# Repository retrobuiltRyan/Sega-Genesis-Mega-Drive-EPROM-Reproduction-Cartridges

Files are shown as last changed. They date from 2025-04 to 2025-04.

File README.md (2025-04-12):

# Sega-Genesis-Mega-Drive-EPROM-Reproduction-Cartridges
https://youtu.be/jw_2mUTdxVY

P1010174 - Copy

Solder Jumper example

Sega Genesis MegaDrive EPROM Cart PCB

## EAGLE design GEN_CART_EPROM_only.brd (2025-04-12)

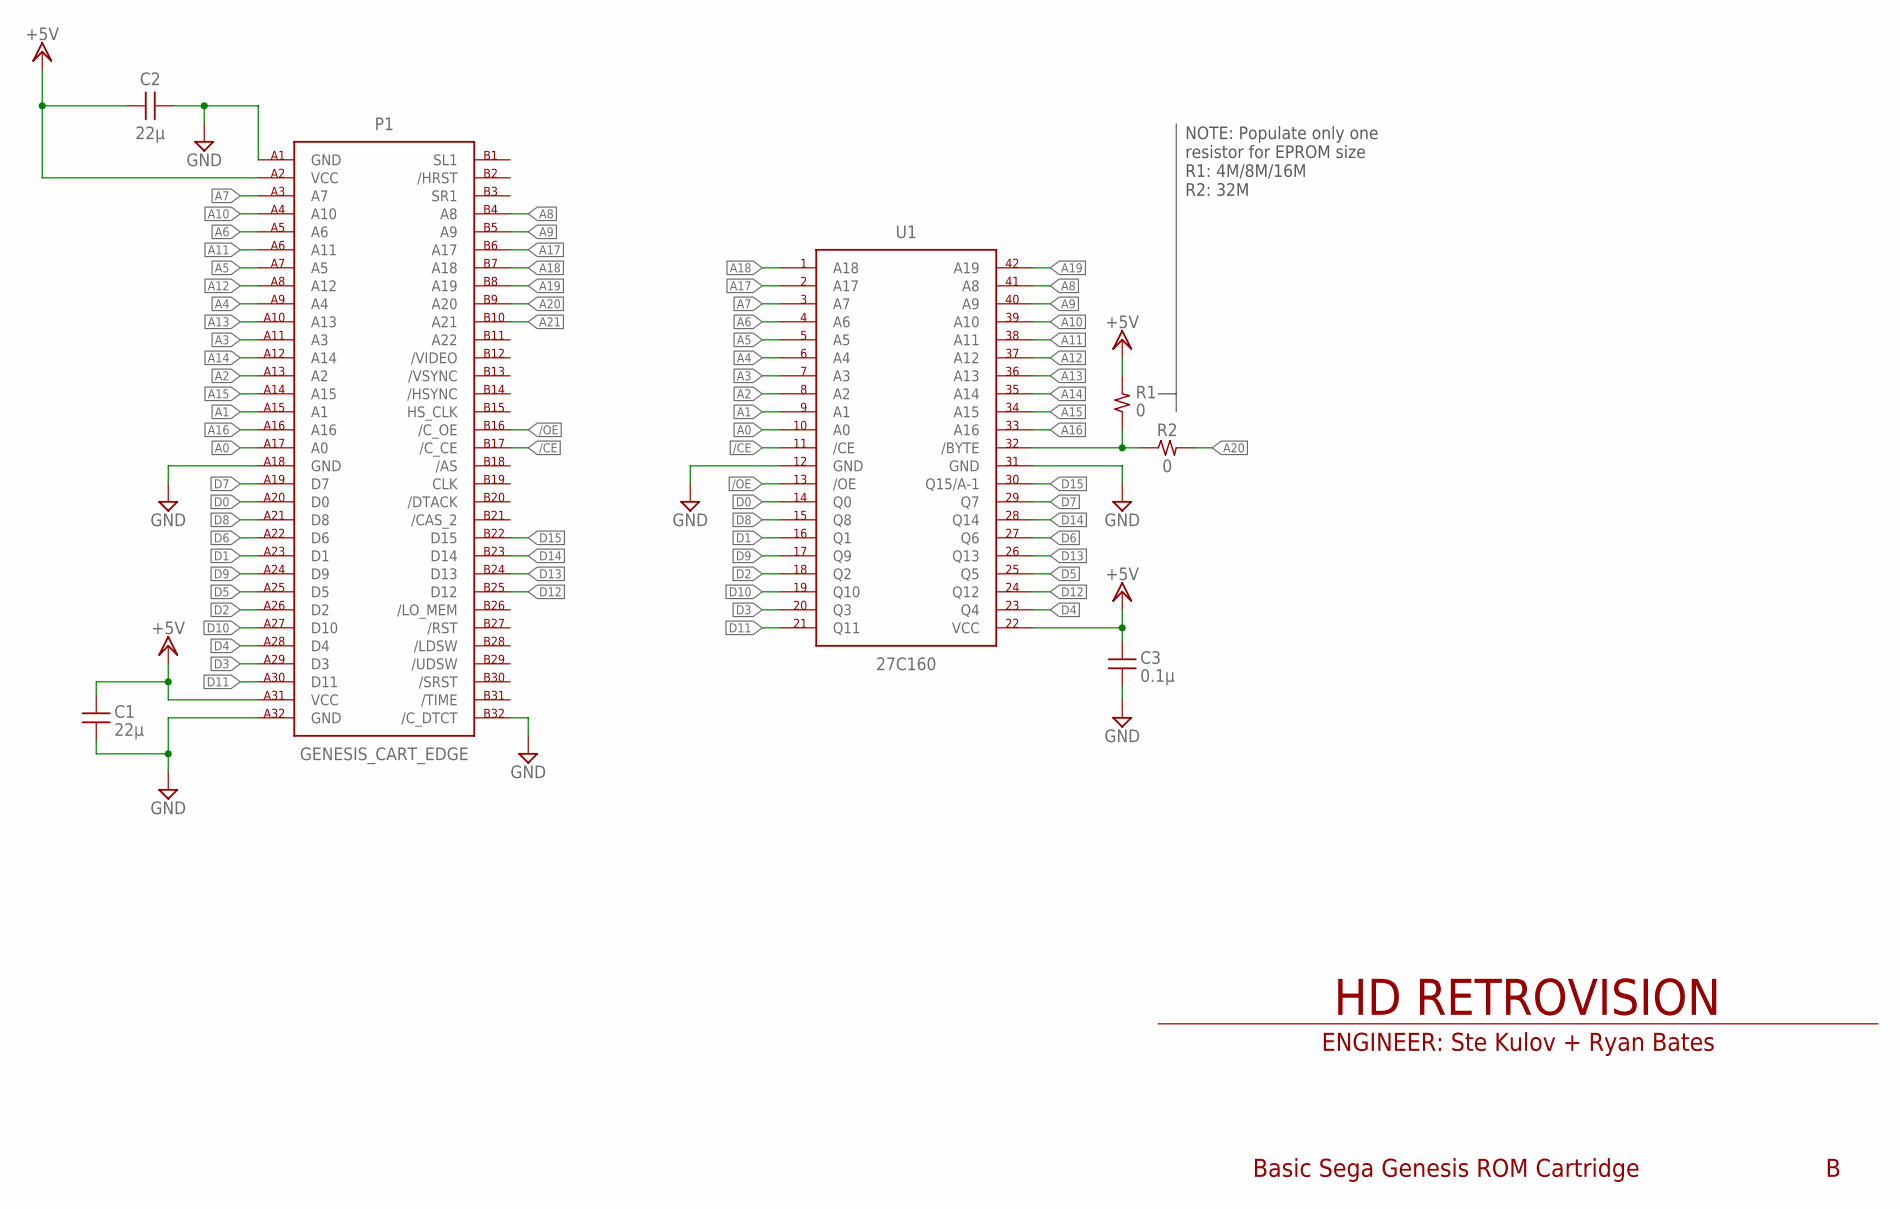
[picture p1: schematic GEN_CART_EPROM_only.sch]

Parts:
C1, C2: 22µ; CAP_SMD1210
C3: 0.1µ; CAP_SMD1210
P1: GENESIS_CART_EDGE
R1, R2: 0; RES_SMD0603
U1: 27C160; DIP_600MIL_42

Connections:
/CE: P1.B17 (/C_CE), U1.P$11 (/CE)
/OE: P1.B16 (/C_OE), U1.P$13 (/OE)
A0: P1.A17 (A0), U1.P$10 (A0)
A1: P1.A15 (A1), U1.P$9 (A1)
A2: P1.A13 (A2), U1.P$8 (A2)
A3: P1.A11 (A3), U1.P$7 (A3)
A4: P1.A9 (A4), U1.P$6 (A4)
A5: P1.A7 (A5), U1.P$5 (A5)
A6: P1.A5 (A6), U1.P$4 (A6)
A7: P1.A3 (A7), U1.P$3 (A7)
A8: P1.B4 (A8), U1.P$41 (A8)
A9: P1.B5 (A9), U1.P$40 (A9)
A10: P1.A4 (A10), U1.P$39 (A10)
A11: P1.A6 (A11), U1.P$38 (A11)
A12: P1.A8 (A12), U1.P$37 (A12)
A13: P1.A10 (A13), U1.P$36 (A13)
A14: P1.A12 (A14), U1.P$35 (A14)
A15: P1.A14 (A15), U1.P$34 (A15)
A16: P1.A16, U1.P$33 (A16)
A17: P1.B6 (A17), U1.P$2 (A17)
A18: P1.B7 (A18), U1.P$1 (A18)
A19: P1.B8 (A19), U1.P$42 (A19)
A20: P1.B9 (A20), R2.P$2 (2)
A21: P1.B10 (A21)
D0: P1.A20 (D0), U1.P$14 (Q0)
D1: P1.A23 (D1), U1.P$16 (Q1)
D2: P1.A26 (D2), U1.P$18 (Q2)
D3: P1.A29 (D3), U1.P$20 (Q3)
D4: P1.A28 (D4), U1.P$23 (Q4)
D5: P1.A25 (D5), U1.P$25 (Q5)
D6: P1.A22 (D6), U1.P$27 (Q6)
D7: P1.A19 (D7), U1.P$29 (Q7)
D8: P1.A21 (D8), U1.P$15 (Q8)
D9: P1.A24 (D9), U1.P$17 (Q9)
D10: P1.A27 (D10), U1.P$19 (Q10)
D11: P1.A30 (D11), U1.P$21 (Q11)
D12: P1.B25 (D12), U1.P$24 (Q12)
D13: P1.B24 (D13), U1.P$26 (Q13)
D14: P1.B23 (D14), U1.P$28 (Q14)
D15: P1.B22 (D15), U1.P$30 (Q15/A-1)
GND: C1.P$1, C2.P$1, C3.P$1, P1.A1 (GND), P1.A18 (GND), P1.A32 (GND), P1.B32 (/C_DTCT), U1.P$12 (GND), U1.P$31 (GND)
unnamed: R1.P$1 (1), R2.P$1 (1), U1.P$32 (/BYTE)
V+: C1.P$2, C2.P$2, C3.P$2, P1.A2 (VCC), P1.A31 (VCC), R1.P$2 (2), U1.P$22 (VCC)

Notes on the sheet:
HD RETROVISION
Basic Sega Genesis ROM Cartridge
ENGINEER: Ste Kulov + Ryan Bates
NOTE: Populate only one resistor for EPROM size R1: 4M/8M/16M R2: 32M

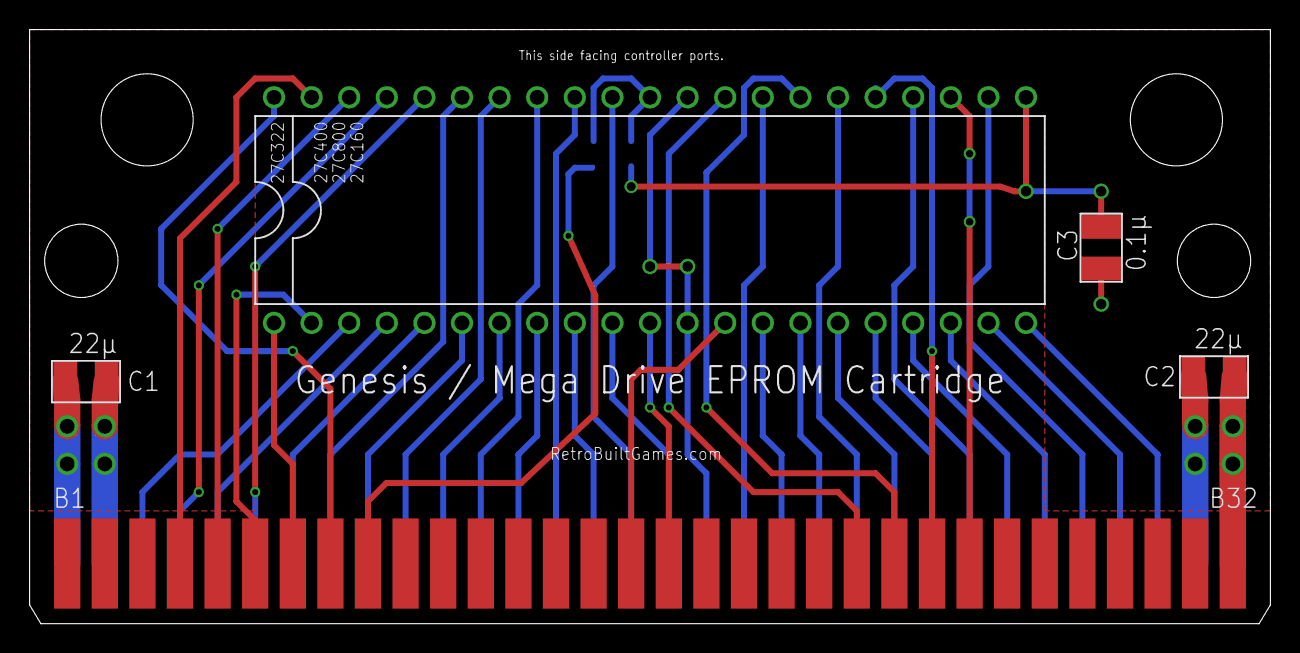
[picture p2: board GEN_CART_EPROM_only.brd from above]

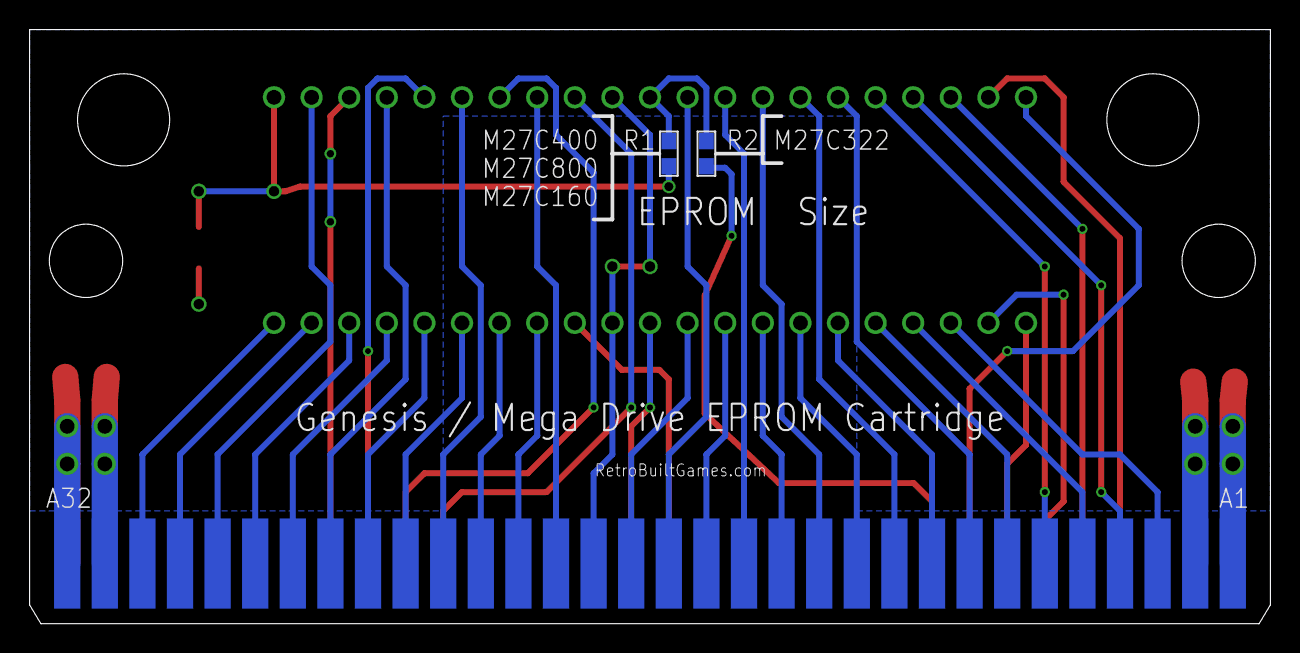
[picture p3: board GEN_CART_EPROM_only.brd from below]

Board: 2 copper layers, 83.8 x 40.1 mm, 7 parts (2 on the bottom side), 42 nets.
